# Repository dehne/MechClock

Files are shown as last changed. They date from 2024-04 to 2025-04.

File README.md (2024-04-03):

# MechClock – An Electromechanical Seven-Segment Clock Display Driven by a RaspberryPi Pico-W

# Introduction

Inspired by a [project](https://www.instructables.com/Kinetic-Digital-Clock-Arduino-3D-Print/) on the Hackaday blog that implements an seven-segment digital clock featuring 3D-printed display digits with protruding segments, each segment driven in or out by a hobby servo, I decided to make a clock with a similar display implemented very differently. Instead of servos, I chose to drive each digit's seven segments using seven cams, all ganged together on single shaft driven by a small, geared-down 28BYJ-48 stepper motor. One turn of the common cam shaft drives the display to show the digits 0 - 9 in sequence. Four identical digit display modules side by side with a fixed colon unit in the middle complete the display. Add a custom PCB with a RaspberryPi Pico-W, 3 ULN2003 Darlington pair DIP chips to drive the steppers, and an LED array/light sensor for self adjusting digit illumination, a case and some custom firmware, and whaddya know: a digital clock.

Here you'll find the firmware for the project.

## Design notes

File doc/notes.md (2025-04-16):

# Notes While Developing

I've been seeing occasional hangs in stepping the motors. To track the source down I implemented a watchdog in ULN2003Pico's repeating timer callback. It just barked:

```
> status
WiFi is connected, system clock is set, test is off.
At 0:25:27 UTC displayed moon phase is 13/60, actual moon phase is 13/60, next phase change is in 10:05:56.
Watchdog barked. It said: Motor was 0, curMicros was 2595401951, microsNextStep was 3931967850, steps to go was 144
```

Interesting. curMicros is nowhere near crossing 0 (4294967295 --> 0), but microsNextStep is a bizarrely long way in the future.

Added "volatile" to the other variables used in the repeating timer callback. Then, after several cycles without trouble, got:

```
> status
WiFi is connected, system clock is set, test is off.
At 17:01:49 UTC displayed moon phase is 16/60, actual moon phase is 16/60, next phase change is in 4:55:45.        
Watchdog barked. It said: Motor was 0, curMicros was 269542184, microsNextStep was 1994201537, steps to go was 164.
```

Again, very strange. So, I'm wondering if the callback isn't always getting called back in a timely way. So I implemented more watchdog code looking, this time, for a delay in the execution of the callback. Here's what it said:

```
> status
WiFi is connected, system clock is set, test is off.
At 0:07:05 UTC displayed moon phase is 17/60, actual moon phase is 17/60, next phase change is in 9:39:13.
Watchdog barked: Callback delayed. curMicros was 833180873, lastCurMicros 833138087.
```
Yes, it got called back 42786 μs after the last one, not 512 μs plus or minus a few. And in another test it came in at 40947 μs. I've been pretty careful about not keeping interrupts disabled for anything like that long. 

Poking around on the interwebs I found [this](https://forums.raspberrypi.com/viewtopic.php?p=2142153&hilit=repeating_timer_callback#p2142153) which hints at odd behavior "When I add the timer with add_repeating_timer_us() to the default alarm pool, the callback isn't called anymore after some while. (Minutes to hours, depends on config.) When I create a separate alarm pool, everything is fine." Not my behavior exactly, but maybe look into "creating a separate pool?"

That was easy enough. Now we'll see if the watchdog barks. Well, some days later I got:

```
Watchdog barked: Late to callback. Motor was 0, microsNextStep was 1874762412, steps to go was 0, curMicros was 1943459845, lastCurMicros was 1943420031.
```

So, even with its own alarm pool, the callback got invoked late after something like 3 days. 39122 μs late. About the same as with the default pool. Huh. I wonder what the circumstances could be. 

I'd guess it comes from some thread turning off interrupts for a longish stretch. 39-40 ms is a pretty long stretch, though. I don't think it's me since the error occurred when the steps-to-go for the ls motor was 0. That means the callback was doing almost nothing and, since nothing else interesting was going on, only the same old same old was going on in my code. No interrupts being disabled. I'd guess its in either WiFi or NTP.

Does it really matter all that much to me in this application? I'm guessing not. I'll check around to see if it's been reported, but in the meantime, let's ignore this sort of glitch for now.

Hmmm. I don't see anything reported on [github](https://github.com/raspberrypi/pico-sdk/issues?page=1&q=is%3Aissue+callback) that looks similar to what I'm seeing. Maybe write a super simple test case to see if it turns up. Then add WiFi, and then NTP to see if I can provoke it? How much of a community helper do I feel like being? Answer: Not enough to set up a test environment in platformio that's based on the very latest SDK. Getting it wo work with Earl Pilhower's setup was tough enough.

Several days later, and after going past full moon, the watchdog is still sleeping. Several more days and still sleeping. Now more than a month later, it's still working flawlessly. Time to change the firmware to store the data persistently if the watchdog barks so that I can hang the clock up and let it run but still access debugging data if something happens.

Many months later and the watchdog never barked after loosening the criteria. So, no it doesn't really matter. Curious, though.

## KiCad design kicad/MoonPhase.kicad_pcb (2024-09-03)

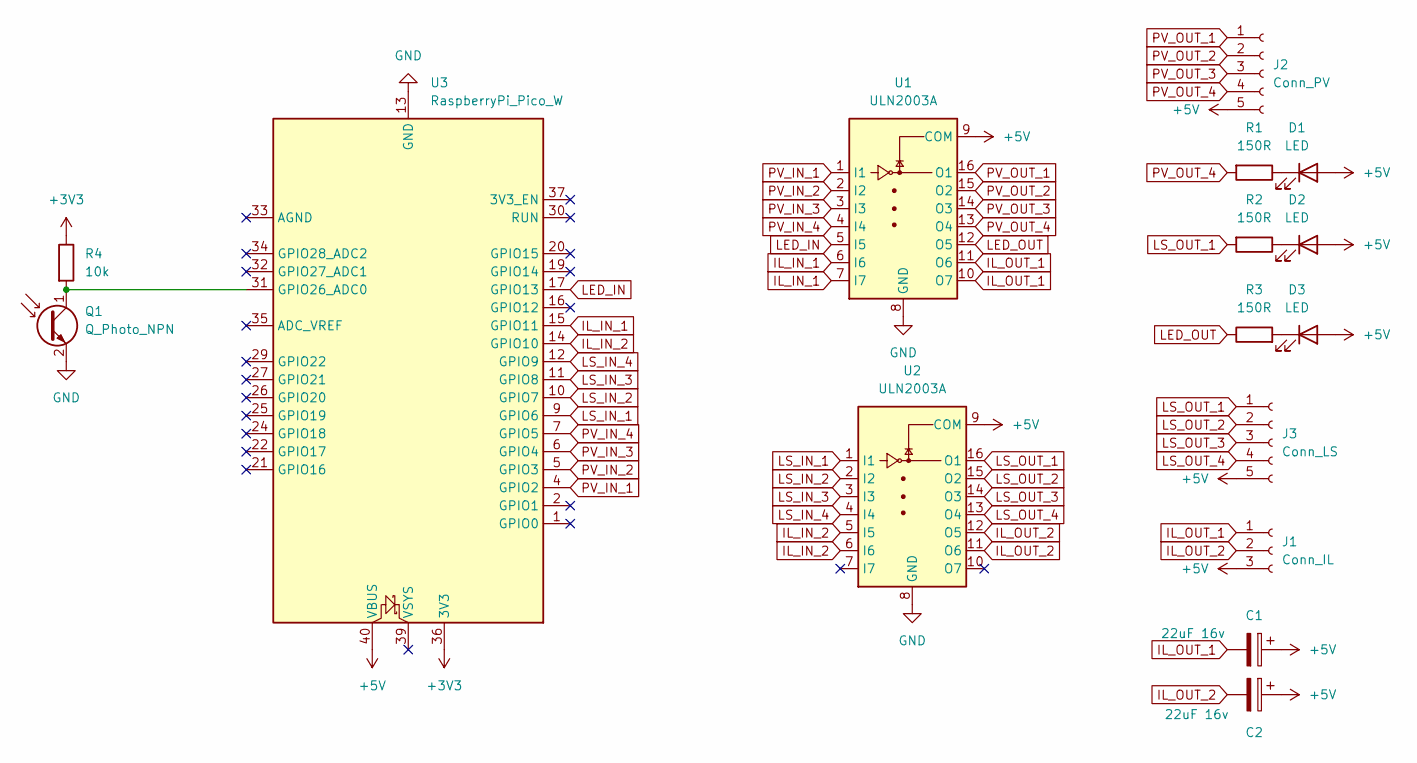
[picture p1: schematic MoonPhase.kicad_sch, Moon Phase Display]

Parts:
C1, C2: 22uF 16v; CP_Radial_D4.0mm_P2.00mm
D1, D2, D3: LED; LED_0805_2012Metric
J1: Conn_IL; JST_XH_B3B-XH-AM_1x03_P2.50mm_Vertical
J2: Conn_PV; JST_XH_B5B-XH-AM_1x05_P2.50mm_Vertical
J3: Conn_LS; JST_XH_B5B-XH-AM_1x05_P2.50mm_Vertical
Q1: Q_Photo_NPN; PinHeader_1x02_P2.54mm_Vertical
R1, R3: 150R; R_0805_2012Metric
R2: 150R; R_0805_2012Metric_Pad1.20x1.40mm_HandSolder
R4: 10k; R_0805_2012Metric
U1, U2: ULN2003A; CERDIP-16_W7.62mm_SideBrazed_Socket
U3: RaspberryPi_Pico_W; RaspberryPi_Pico_Common

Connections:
+3V3: R4.1, U3.36 (3V3)
+5V: C1.1, C2.1, D1.2 (A), D2.2 (A), D3.2 (A), J1.3, J2.5, J3.5, U1.9 (COM), U2.9 (COM), U3.40 (VBUS)
GND: Q1.2 (E), U1.8 (GND), U2.8 (GND), U3.3 (GND), U3.8 (GND), U3.13 (GND), U3.18 (GND), U3.23 (GND), U3.28 (GND), U3.38 (GND)
IL_IN_1: U1.6 (I6), U1.7 (I7), U3.15 (GPIO11)
IL_IN_2: U2.5 (I5), U2.6 (I6), U3.14 (GPIO10)
IL_OUT_1: C1.2, J1.1, U1.10 (O7), U1.11 (O6)
IL_OUT_2: C2.2, J1.2, U2.11 (O6), U2.12 (O5)
LED_IN: U1.5 (I5), U3.17 (GPIO13)
LED_OUT: R3.1, U1.12 (O5)
LS_IN_1: U2.1 (I1), U3.9 (GPIO6)
LS_IN_2: U2.2 (I2), U3.10 (GPIO7)
LS_IN_3: U2.3 (I3), U3.11 (GPIO8)
LS_IN_4: U2.4 (I4), U3.12 (GPIO9)
LS_OUT_1: J3.1, R2.2, U2.16 (O1)
LS_OUT_2: J3.2, U2.15 (O2)
LS_OUT_3: J3.3, U2.14 (O3)
LS_OUT_4: J3.4, U2.13 (O4)
unnamed: D1.1 (K), R1.1
unnamed: D2.1 (K), R2.1
unnamed: D3.1 (K), R3.2
unnamed: Q1.1 (C), R4.2, U3.31 (GPIO26_ADC0)
PV_IN_1: U1.1 (I1), U3.4 (GPIO2)
PV_IN_2: U1.2 (I2), U3.5 (GPIO3)
PV_IN_3: U1.3 (I3), U3.6 (GPIO4)
PV_IN_4: U1.4 (I4), U3.7 (GPIO5)
PV_OUT_1: J2.1, U1.16 (O1)
PV_OUT_2: J2.2, U1.15 (O2)
PV_OUT_3: J2.3, U1.14 (O3)
PV_OUT_4: J2.4, R1.2, U1.13 (O4)

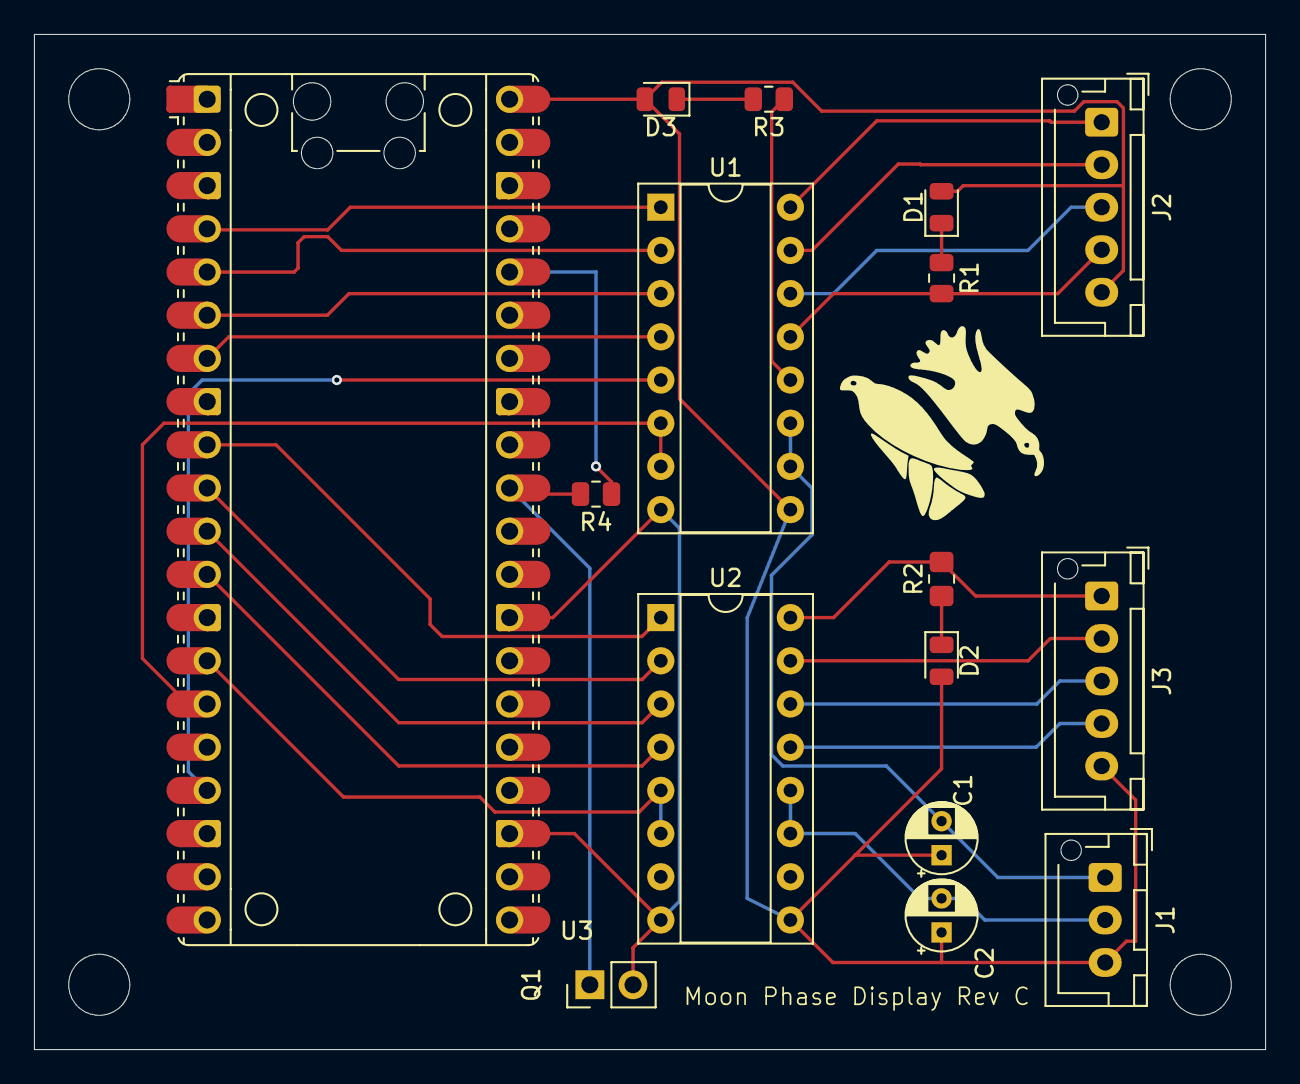
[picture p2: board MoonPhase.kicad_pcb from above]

Board: 2 copper layers, 72.4 x 59.7 mm, 16 parts (0 on the bottom side), 29 nets.

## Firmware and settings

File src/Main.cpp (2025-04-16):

/****
 * @file main.cpp
 * @version 1.1.1
 * @date April 2025
 * 
 * This is the firmware for a moon phase display. It uses the Arduino framework and runs on a 
 * Raspberry Pi Pico W. See MoonDisplay.h for details on ahow the display works display. 
 * 
 * The basic function here is overall control of the device. In particular
 * 
 *      * Managing persistent state:
 *          - Info needed to connect to WiFi for NTP access
 *          - Timezone info. (So we can talk in local time.)
 *          - The current phase that the MoonDisplay is showing. (So that we can pick up again 
 *            where we left off after a reboot. Updated each time we move the display.)
 *          - Whether we're in "test" mode. (In test mode we don't move the display.)
 *          - The ambient light level limits. (Below the min, lights are off, above the max, 
 *            lights are fuly on.)
 *          - Optionally, depending on a #define, watchdog data for the ULN2003Pico stepper 
 *            library. (I was having trouble with delays in receiving iterrupts for a while.)
 *      * Setting and maintaining the current time using WiFi, NTP and the system time() 
 *        functions. 
 *      * Blinking an LED to show we're alive.
 *      * Initializing the MoonDisplay from persistent storage and then letting it run().
 *      * Setting up and running command-line interpreter to let someone adjust and inspect the 
 *        device.
 * 
 *****
 * 
 * Copyright (C) 2024-2025 D.L. Ehnebuske
 * 
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
 ****/
#include <Arduino.h>                                    // Basic Arduino framework stuff
#include <EEPROM.h>                                     // EEPROM emulation for the Pico
#include <WiFi.h>                                       // Pico WiFi support
#include <CommandLine.h>                                // Terminal command line support
#include <MoonDisplay.h>                                // The moon display mechanism
#include <ULN2003Pico.h>                                // ULN2003Pico stepper motor drivers (only used for watchdog)

//#define DEBUG                                           // Uncomment to enable debug printing

#define FINGERPRINT         (0x1656)                    // Our fingerprint (to see if EEProm has our stuff)
#define PAUSE_MILLIS        (500)                       // millis() to pause between various initialization retries
#define BLINK_ON_MILLIS     (50)                        // millis() LED blinks on to show we're actually running
#define BLINK_OFF_MILLIS    (10000)                     // millis() LED blinks off to show we're actually running
#define SERIAL_WAIT_MS      (20000)                     // millis() to wait for Serial to begin before charging ahead
#define WIFI_CONN_MAX_RETRY (3)                         // How many times to retry WiFi.begin() before giving up
#define NTP_MAX_RETRY       (20)                        // How many times to retry getting the system clock set by NTP
#define CONFIG_ADDR         (0)                         // Address of config structure in persistent memory
#define WD_DATA_ADDR        sizeof(nvState_t)           // Address of watchdog data structure in persistent memory
#define BANNER              "MoonDisplay V1.1.0"        // Hello World message
#define LUNAR_MONTH         (29.53059)                  // The (average) length of the lunar cycle in days
#define PHASE_MILLIS        (42524050)                  // The interval in ms between display phase changes (29.53059/60 days)

#define TIMEZONE            "PST8PDT,M3.2.0,M11.1.0"    // Default time zone definition in POSIX format

#define LED                 (LED_BUILTIN)               // Use the LED attached to this pin

// Stepper motor pin definitions
#define PV_IN1              (2)                         // Pivot motor
#define PV_IN2              (3)
#define PV_IN3              (4)
#define PV_IN4              (5)
#define LS_IN1              (6)                         // Leadscrew motor
#define LS_IN2              (7)
#define LS_IN3              (8)
#define LS_IN4              (9)

// Illuminator pin definitions
#define IL_IN1              (11)                        // Waxing COB pin
#define IL_IN2              (10)                        // Waning COB pin
#define IL_IN3              (26)                        // Phototransistor pin

/****
 *  Type definitions
 ****/
struct nvState_t {  // Type definition for configuration data stored in "EEPROM" (actually flash memory in the rp2040)
    int16_t fingerprint;                // Value to tell whether EEPROM contents is ours
    char ssid[33];                      // The WiFi SSID
    char pw[33];                        // The WiFi password
    char timezone[49];                  // The timezone in POSIX format
    int16_t curPhase;                   // The currently displayed phase
    boolean testing;                    // True if in testing mode false if running normally
    uint8_t loAmbient;                  // Ambient light lower limit
    uint8_t hiAmbient;                  // Ambient light upper limit
};

/****
 * Constants
 ****/
// A tm structure defining a time that's earlier than now: Jan 1, 2024
// Make it this way because C time_t values are, technically, opaque
struct tm tmDawnOfHistory {
    .tm_sec = 0,            // tm_sec is 0-based
    .tm_min = 0,            // tm_min is 0-based
    .tm_hour = 0,           // tm_hour is 0-based
    .tm_mday = 1,           // tm_mday is 1-based
    .tm_mon = 1 - 1,        // tm_mon is 0-based
    .tm_year = 2024 - 1900, // tm_year is 1900-based
    .tm_isdst = 0
};
const time_t dawnOfHistory = mktime(&tmDawnOfHistory);

// There was a new moon at 22:57UTC on JUly 5, 2024. That's what we'll use as the first new moon
struct tm tmFirstNewMoon {
    .tm_sec = 0,            // tm_sec is 0-based
    .tm_min = 57,           // tm_min is 0-based
    .tm_hour = 22,          // tm_hour is 0-based
    .tm_mday = 5,           // tm_mday is 1-based
    .tm_mon = 7 - 1,        // tm_mon is 0-based
    .tm_year = 2024 - 1900, // tm_year is 1900-based
    .tm_isdst = 0
};
const time_t firstNewMoon = mktime(&tmFirstNewMoon);

const nvState_t defaultState = {
    .fingerprint = FINGERPRINT,     // How we recognize the content as ours
    .ssid = "Set the SSID",         // Place holder for SSID
    .pw = "Set the PW",             // Place holder for Password
    .timezone = TIMEZONE,           // Default for timezone
    .curPhase = 0,                  // Default for the current phase number
    .testing = true,                // Default for whether we're in testing mode or not
    .loAmbient = 4,                 // Default lower ambient light limit
    .hiAmbient = 75                 // Default upper ambient light limit
};

// GPIO pins for pivot motor, leadscrew motor, and the Illuminator's two LED COBs and its phototransistor
const byte p[4] = {PV_IN1, PV_IN2, PV_IN3, PV_IN4};
const byte l[4] = {LS_IN1, LS_IN2, LS_IN3, LS_IN4};
const byte i[3] = {IL_IN1, IL_IN2, IL_IN3};

/****
 * Global variables
 ****/
MoonDisplay display(p, l, i);                           // The moon phase display
CommandLine ui;                                         // Command line interpreter object
nvState_t state;                                        // Non-volatile (EEPROM) state
unsigned long nextPhaseChangeMillis;                    // millis() at next phase change
boolean eStop;                                          // True if emergency stop needed, false otherwise
bool haveSavedState;                                    // True if we have a saved state
bool wifiIsUp;                                          // True if we got connected to Wifi
bool clockIsSet;                                        // True if we managed to get the system clock set via WiFi, Internet and NTP

/**
 * @brief   Returns true if a comes "before" b in unsigned long modulo arithmetic. Basically, if 
 *          it's shorter to go "forward" from a to b than it is to go "backward" from a to b.
 * 
 * @param a
 * @param b 
 * @return  true    a comes before b
 * @return  false   a does not come before b
 */
inline bool isBefore(unsigned long a, unsigned long b) {
    return (a - b) > (b - a);
}

/**
 * @brief   Return the "moon age" in seconds at the specified time, t. I.e., the number of seconds 
 *          that have passed since the new moon previous to t
 * 
 * @param t         The time_t for which the moon age is required
 * @return int32_t  The age of the moon in seconds at t
 */
int32_t moonAgeSecsAt(time_t t) {
    uint32_t secSinceFirstNewMoon = static_cast<uint32_t>(difftime(t, firstNewMoon));
    // The number of seconds since the last new moon is mod(secSinceFirstNewMoon, <lunar month length in secs>)
    return static_cast<int32_t>(secSinceFirstNewMoon % static_cast<int32_t>(LUNAR_MONTH * 86400));
}

/**
 * @brief Get the phase (0-59) of the moon at the specifed time.
 * 
 * NB:  The specified time must be on or after firstNewMoon (22:57UTC on July 5, 2024).
 * 
 * @param t         time_t time for which the phase is required
 * @return int16_t  The phase (0-59) at the specified time
 */
int16_t moonPhaseAt(time_t t) {
    // The required phase is 60 * <moon age in sec> / <length of the lunar month in sec> ('cause we're using 60 phases/lunation)
    return static_cast<int16_t>(moonAgeSecsAt(t) / static_cast<int32_t>(LUNAR_MONTH * 1440.0));
}

unsigned long getNextPhaseChangeMillis() {
    time_t now = time(nullptr);
    int32_t millisSincePhaseChange = (moonAgeSecsAt(now) * 1000) - (moonPhaseAt(now) * PHASE_MILLIS);
    int32_t nextPhaseChangeMillisFromNow = PHASE_MILLIS - millisSincePhaseChange;
    return millis() + nextPhaseChangeMillisFromNow;
}

/**
 * @brief Connect to the WiFi network using state.ssid for the SSID and state.pw for the password
 * 
 * @return true     Success
 * @return false    Failure
 */
bool connectToWifi() {
    int8_t retryCount = 0;
    while (WiFi.status() != WL_CONNECTED && retryCount < WIFI_CONN_MAX_RETRY) {
        WiFi.begin(state.ssid, state.pw);
        if (WiFi.status() != WL_CONNECTED) {
            if (++retryCount >= WIFI_CONN_MAX_RETRY) {
                return false;   // Give up on connecting to WiFi
            }
        }
    }
    return true;
}

/**
 * @brief   Get the time from an NTP server and set the Pico's system clock from that
 * 
 * @return true     All went well
 * @return false    Couldn't get the time from an NTP server
 */
bool setSysTimeFromNTP() {
    time_t now;
    setenv("TZ", state.timezone, 1);               // Do POSIX ritual to make local time be our time zone
    tzset();
    NTP.begin("pool.ntp.org", "time.nist.gov");     // Set system clock with current epoch using NTP
    int8_t retryCount = 0;
    while ((now = time(nullptr)) < dawnOfHistory && ++retryCount < NTP_MAX_RETRY) {
        delay(PAUSE_MILLIS);
    }
    if (retryCount >= NTP_MAX_RETRY) {
        return false;
    }
    return true;
}

#ifdef UL_WATCHDOG
String formatWdData(wdData_t wdData) {
    if (!wdData.watchdogBarked) {
        return "Watchdog did not bark.\n";
    }
    return "Watchdog barked: " +
        (wdData.watchdogAlarmType == STEP_TIME ? String("Unreasonable step time") : wdData.watchdogAlarmType == CALLBACK ? String("Late to callback") : String("Next step already missed")) + 
        ". Motor was " + String(wdData.watchdogMotor) + ", microsNextStep was " + String(wdData.watchdogMns) + 
        ", steps to go was " + String(wdData.watchdogStg) + ", curMicros was " + String(wdData.watchdogCurMicros) + 
        ", lastCurMicros was " + String(wdData.watchdogLastCurMicros) + ".\n";
}
#endif

/**
 * @brief Get the status of the device as a String
 * 
 * @return String   The device status
 */
String getStatus() {
    String answer = 
        String("WiFi is ") + (wifiIsUp ? "" : "not" ) + "connected, system clock is " + (clockIsSet ? "" : "not ") + 
        "set, test is " + (state.testing ? "on.\n" : "off.\n");
    if (clockIsSet) {
        time_t now = time(nullptr);
        tm *nowTm = gmtime(&now);
        int32_t secToPC = (nextPhaseChangeMillis - millis()) / 1000;
        String hourPC = String(secToPC / 3600);
        String minPC = String((secToPC % 3600) / 60);
        String secPC = String(secToPC % 60);
        answer += 
            "At " + String(nowTm->tm_hour) + ":" + (nowTm->tm_min < 10 ? "0" : "") + 
            String(nowTm->tm_min) + ":" + (nowTm->tm_sec < 10 ? "0" : "") + String(nowTm->tm_sec) + " UTC displayed moon phase is " + 
            String(display.getPhase()) + "/60, actual moon phase is " + String(moonPhaseAt(now)) + "/60, next phase change is in " + 
            hourPC + ":" + (minPC.length() < 2 ? "0" : "") + minPC + ":" + (secPC.length() < 2 ? "0" : "") + secPC + ".\n";
    } else {
        answer += "Displayed moon phase is " + String(display.getPhase()) + ".\n";
    }
    #ifdef UL_WATCHDOG
    wdData_t wdData = EEPROM.get(WD_DATA_ADDR, wdData);
    answer += formatWdData(wdData);
    #endif
    return answer;
}

/**
 * @brief help command handler: Display command summary
 * 
 * @param h         Pointer to CommandHandlerHelper object
 * @return String   The String to dsiplay
 */
String onHelp(CommandHandlerHelper *h) {
    return
        "help                   Display this text to the user\n"
        "h                      Same as \"help\"\n"
        "ambient [<lo> <hi>]    Display or set lower and upper ambient light limits\n"
        "                         0 <= lo < hi <= 100\n"
        "assume <phase>         Assume moon display is showing phase <phase>\n"
        "ls [<steps>]           Drive leadscrew by <steps>. + ==> out, - ==> in\n"
        "pv [<steps>]           Drive pivot by <steps>. + ==> CC, - ==> CW viewed from front\n"
        "save                   Save the current configuration data in persistent memory.\n"
        "                       Until a save is done or the phase of the moon changes,\n"
        "                       configuration changes are not made persistent.\n"
        "show <phase>           Make moon display show phase <phase>\n"
        "status                 Display the system's status.\n"
        "stop                   Stop all moon display motion immediately\n"
        "s                      Same as \"stop\"\n"
        "test [on|off]          Set or display whether we're in test mode\n"
        "tz [<POSIX tz>]        Set or display the POSIX-format timeszone to use.\n"
        "                       Save configuration to make persistent.\n"
        #ifdef UL_WATCHDOG
        "watchdog               Display and the reset the persistent watchdog data.\n"
        #endif
        "wifi                   Display the current ssid and pw.\n"
        "wifi pw <password>     Set the WiFi password to <password>.\n"
        "                       Save to make persistent.\n"
        "wifi ssid <ssid>       Set the WiFi SSID we should use to <ssid>\n"
        "                       Save to make persistent.\n";
}

String onAmbient(CommandHandlerHelper *h) {
    String arg1 = h->getWord(1);
    if (arg1.length() == 0) {
        return "Current ambient light level is " + String(display.getAmbient()) + ", lowerLimit; " + String(state.loAmbient) + 
            ", upper limit: " + String(state.hiAmbient) + "\n";
    }
    int16_t lowerLimit = arg1.toInt();
    int16_t upperLimit = h->getWord(2).toInt();
    if (lowerLimit < 0 || upperLimit > 100 || upperLimit <= lowerLimit) {
        return "Ambient limits must be: 0 >= lower < upper <= 100\n";
    }
    state.loAmbient = lowerLimit;
    state.hiAmbient = upperLimit;
    display.setAmbientLimits(lowerLimit, upperLimit);
    return "Ambient limits set to " + String(lowerLimit) + " " + String(upperLimit) + "\n";
}

/**
 * @brief   assume <phase> command handler: Assume display is showing phase <phase> and that's 
 *          where we are and want to be.
 * 
 * @param h         CommandLineHelper to talk to command processor
 * @return String   What command processor should show to the user
 */
String onAssume(CommandHandlerHelper *h) {
    int16_t phase = h->getWord(1).toInt();
    if (phase < 0 || phase >= 60) {
        return "Phase must be 0 .. 59\n";
    }
    state.curPhase = phase;
    display.assume(phase);
    EEPROM.put(CONFIG_ADDR, state);
    return String("Assumed display shows phase ") + String(phase) + String(EEPROM.commit() ? " and saved\n" : " but unable to save.\n");
}

/**
 * @brief   ls command handler: Drive leadscrew by <steps>. + ==> out, - ==> in,
 *          but don't change thes location the motor thinks it's at
 * 
 * @param h         CommandLineHelper to talk to command processor
 * @return String   What command processor should show to the user
 */
String onLs(CommandHandlerHelper *h) {
    int32_t steps = h->getWord(1).toInt();
    if (steps == 0) {
        return "Leadscrew position: " + String(display.getLs()) + " steps.\n";
    }
    display.turnLs(steps);
    return String("Driving leadscrew by ") + String(steps) + ".\n";
}

/**
 * @brief   pv command handler: Drive pivot by <steps>. + ==> CC, - ==> CW viewed from front, 
 *          but don't change the location the motor thinks it's at.
 * 
 * @param h         CommandLineHelper to talk to command processor
 * @return String   What command processor should show to the user
 */
String onPv(CommandHandlerHelper *h) {
    int32_t steps = h->getWord(1).toInt();
    if (steps == 0) {
        return "Pivot position: " + String(display.getPv()) + " steps.\n";
    }
    display.turnPv(steps);
    return String("Driving pivot by ") + String(steps) + ".\n";
}

/**
 * @brief   'save' command handler: Save the configuration data to persistent memory
 * 
 * @param h         The command handler helper we use to access what the user typed
 * @return String   The result to be displayed to the user
 */
String onSave(CommandHandlerHelper* h) {
    EEPROM.put(CONFIG_ADDR, state);
    return (EEPROM.commit() ? "Configuration saved\n" : "Configuration save failed.\n");
}

/**
 * @brief show <phase> command handler: Change display to show phase <phase>
 * 
 * @param h         CommandLineHelper to talk to command processor
 * @return String   What command processor should show to the user
 */
String onShow(CommandHandlerHelper *h) {
    int16_t phase = h->getWord(1).toInt();
    if (phase < 0 || phase >= 60) {
        return "Phase to show must be 0 .. 59.\n";
    }
    display.showPhase(phase);
    return String("Changing to show phase ") + String(phase) + ".\n";
}

/**
 * @brief status command handler: Report on the system's status
 * 
 * @param h         CommandLineHelper to talk to command processor
 * @return String   What command processor should show to the user
 */
String onStatus(CommandHandlerHelper *h) {
    return getStatus();
}

/**
 * @brief stop and s command handler: Put us in an emergency stop state
 * 
 * @param h         CommandLineHelper to talk to command processor
 * @return String   What command processor should show to the user
 */
String onStop(CommandHandlerHelper *h) {
    display.stop();
    return "Stopping.\n";
}

/**
 * @brief test on|off command handler: Turn test mode on or off
 * 
 * @param h         CommandLineHelper to talk to command processor
 * @return String   What command processor should show to the user
 */
String onTest(CommandHandlerHelper *h) {
    if(h->getWord(1).equalsIgnoreCase("on")) {
        state.testing = true;
        return "Test mode on\n";
    } else if (h->getWord(1).equalsIgnoreCase("off")) {
        state.testing = false;
        nextPhaseChangeMillis = millis();
        return "Test mode off\n";
    } else {
        return String("Test mode is currently ") + (state.testing ? "on\n" : "off\n");
    }
}
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
void loop() {
    static unsigned long nextBlinkMillis = millis() + PAUSE_MILLIS;
    // If we're actually running, deal with blinking the "I'm running" LED
    if (clockIsSet && isBefore(nextBlinkMillis, millis())) {
        if (!state.testing) {
            if(digitalRead(LED) == HIGH) {
                digitalWrite(LED, LOW);
                nextBlinkMillis += BLINK_OFF_MILLIS;
            } else {
                digitalWrite(LED, HIGH);
                nextBlinkMillis += BLINK_ON_MILLIS;
                #ifdef UL_WATCHDOG
                wdData_t wdData = ULN2003WatchdogDump();
                if (wdData.watchdogBarked) {
                    EEPROM.put(WD_DATA_ADDR, wdData);
                    if(!EEPROM.commit()) {
                        Serial.println("Unable to save watchdog data.");
                    }
                }
                #endif
            }
        } else {
            nextBlinkMillis += BLINK_OFF_MILLIS;
        }
    }
     // Let the ui and the display do their thing
    ui.run();
    int16_t newPhase = display.run();
    if (newPhase != -1) {
        state.curPhase = newPhase;
        EEPROM.put(CONFIG_ADDR, state);
        if(!EEPROM.commit()) {
            Serial.println("Moved to new phase, but unable to save!");
        }
    }

    // If the time for a new phase has arrived, deal with it
    if (clockIsSet && isBefore(nextPhaseChangeMillis, millis())) {
        // if we're not testing, actually move the display
        if (!state.testing ) {
            time_t now = time(nullptr);
            int16_t phase = moonPhaseAt(now);
            // If something's already underway, we went off the rails somehow. Stop the world, it's time to get off!
            if (!display.showPhase(phase)) {
                Serial.println("Time for phase change, but things aren't all quiet. Stopping.");
                display.stop();
            }
        }
        nextPhaseChangeMillis = getNextPhaseChangeMillis();
    }
}

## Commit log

2024-04-20 Change display gearing from 1:1 to 2:1
2024-08-20 Bring in kicad, PWM Illuminator
    [MoonPhase-B_Cu.gbr, MoonPhase-B_Mask.gbr, MoonPhase-B_Paste.gbr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]
2024-08-20 Dispose of production files
    [MoonPhase-B_Cu.gbr, MoonPhase-B_Mask.gbr, MoonPhase-B_Paste.gbr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]
2024-08-27 PCB Rev B
    [MoonPhase-B_Cu.gbr, MoonPhase-B_Mask.gbr, MoonPhase-B_Paste.gbr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]
2024-09-03 Add ambient light sensor
2024-09-03 PCB Rev C Update
    [MoonPhase-B_Cu.gbr, MoonPhase-B_Mask.gbr, MoonPhase-B_Paste.gbr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]
